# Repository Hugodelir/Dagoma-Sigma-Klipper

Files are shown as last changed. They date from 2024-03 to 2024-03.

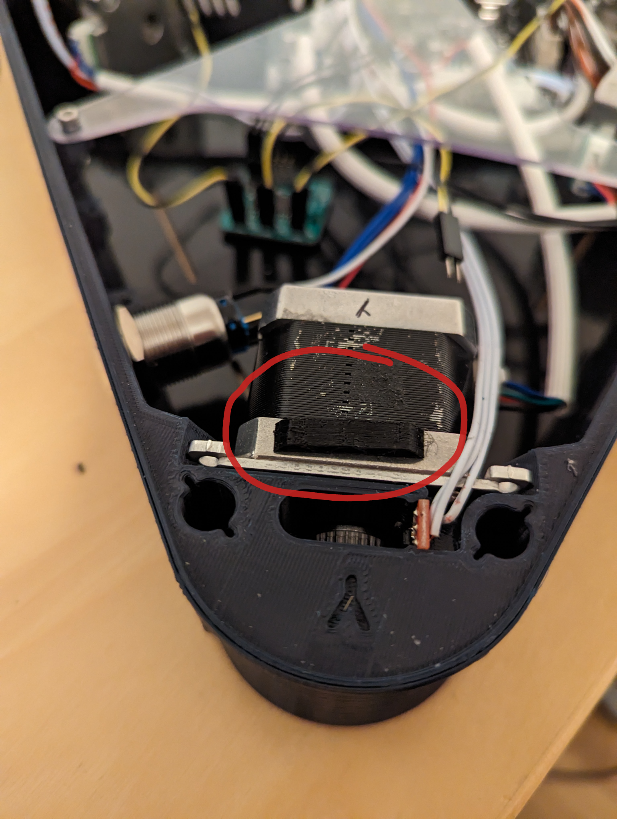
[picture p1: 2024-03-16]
Photo/Cale de rappel FSR.jpg

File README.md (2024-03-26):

Dagoma Sigma avec Klipper

ATTENTION:
Ces modifications nécessitent l'ouverture de la machine avec le risque de détériorer les capteur FSR.
Si vous envisager ces modifications vous perdez la garantie sur votre machine

Le projet à pour objectif de convertir une imprimante Dagoma Sigma utilisant comme firmware Marlin, en une imprimante utilisant comme firmeware Klipper.
afin de gagner en précision et diminuer les bruits de déplacement des chariots
Particularité de cette imprimante utilisation de 3 capteurs de force (FSR) positionnés sous le plateau afin de réaliser le bed leveling, ou Bed-mesk chez Klipper
avec utilisation d'une entrée analogique code adapté de Marlin.

4 étapes envisagé :

1- Electronique et mécanique d'origine, avec utilisation de cale de rappel afin de faire fonctionner les FSR dans la plage de commutation de l'entrée numérique.

2- Electronique et mécanique d'origine, avec ajout d'une carte pour la gestion des FSR qui produit en sortir un signal numérique tout ou rien.
Carte addtionelle utilisé : https://github.com/JohnSL/FSR_Endstop

le 1 et 2 sont des preuve de concepte, pas ou peux de gain attendu coté bruit

3- Mécanique d'origine, pour l'électronique utilisation de la dernière carte D6 avec driver TMC 2209 de chez Dagoma afin de rester dans l'echo système.
gain attendu sur le bruit en augmentant le nombre de micro-step, augmentation limité par la chip 8 bit ATMEGA2560 utiliser sur la carte

4- Mécanique d'origine, pour l'électronique utilisation de la dernière carte Fystec R4 avec la carte additionnelle pour les FSR
Gain attendu plus important sur le bruit, carte optimisé pour embarquer Klipper, form factor plus compact

Eng :
Dagoma Sigma with Klipper

WARNING:
These modifications require opening the machine with the risk of damaging the FSR sensors.
If you consider these modifications you will lose the warranty on your machine.

The project aims to convert a Dagoma Sigma printer using Marlin as firmware, into a printer using Klipper as firmware.
in order to gain precision and reduce carriage movement noise
Particularity of this printer use of 3 force sensors (FSR) positioned under the plate in order to carry out bed leveling, or Bed-mesk at Klipper
with use of an analog input code adapted from Marlin.

4 steps envisaged:

1- Original electronics and mechanics, with use of return wedge in order to operate the FSRs in the switching range of the digital input.

2- Original electronics and mechanics, with the addition of a card for managing the FSR which produces an all or nothing digital signal.
Additional card used: https://github.com/JohnSL/FSR_Endstop

1 and 2 are proof of concept, no or little gain expected in terms of noise

3- Original mechanics, for electronics use of the latest D6 card with TMC 2209 driver from Dagoma in order to remain in the echo system.
expected gain on noise by increasing the number of micro-steps, increase limited by the 8 bit ATMEGA2560 chip used on the card

4- Original mechanics, for electronics use of the latest Fystec R4 card with the additional card for FSR
Greater expected gain on noise, card optimized to embed Klipper, more compact form factor

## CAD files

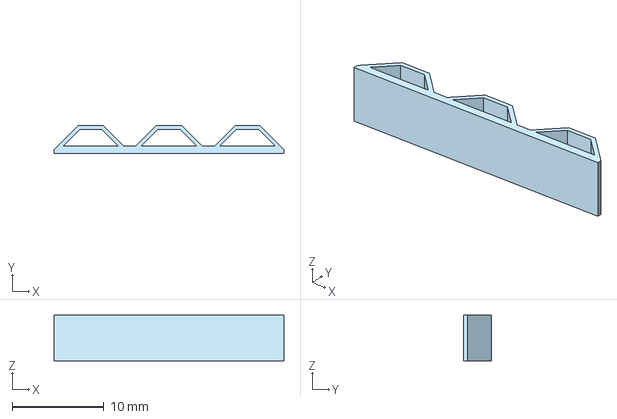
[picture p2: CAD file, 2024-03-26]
CAD/cale FSR Version long.step
25.0 x 3.00 x 5.00 mm

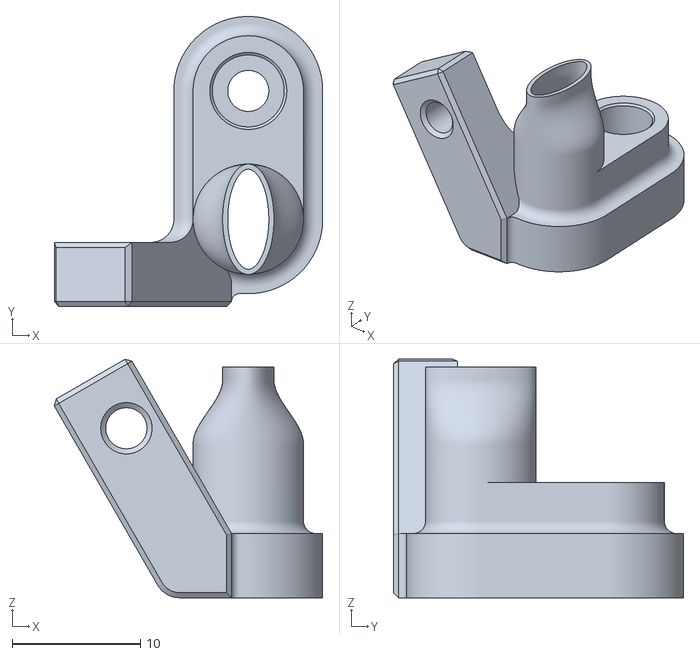
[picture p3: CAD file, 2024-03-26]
STL/Support prise V2 - Part 1.stl
20.9 x 22.6 x 18.6

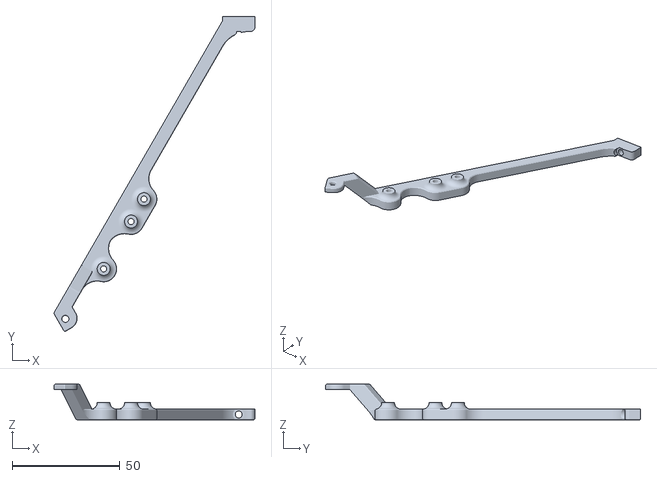
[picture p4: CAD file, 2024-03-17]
STL/support Carte D6 - Part 2.stl
93.2 x 146.3 x 16.6

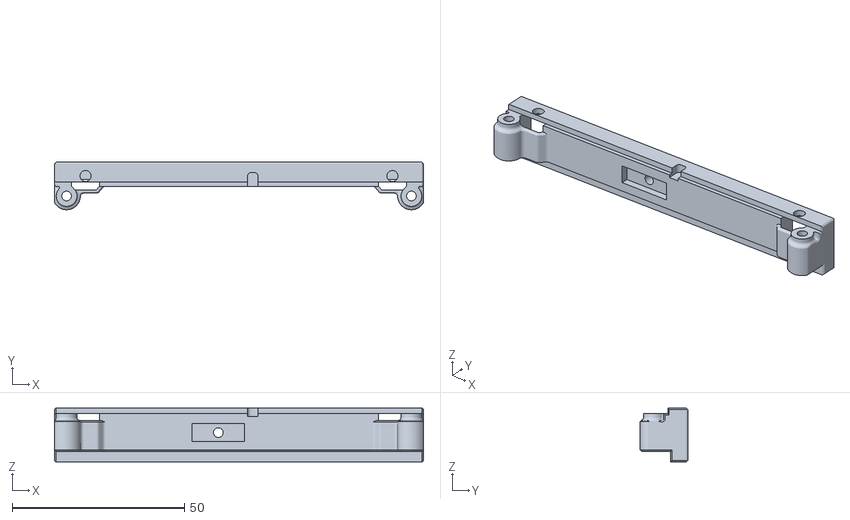
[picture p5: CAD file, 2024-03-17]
STL/support Carte D6 - Part 1.stl
107.0 x 13.8 x 15.6

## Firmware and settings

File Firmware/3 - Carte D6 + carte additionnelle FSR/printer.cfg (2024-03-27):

# !DAGOMA Sigma with Dagoma D6 board
# This file contains common pin mappings for RAMPS (v1.3 and later)
# boards. RAMPS boards typically use a firmware compiled for the AVR
# atmega2560 (though the atmega1280 is also possible).
# See docs/Config_Reference.md for a description of parameters.

# Version Electronique modifier carte Dagoma D6 + carte FSR developper par John SL + cablage adapté
# https://github.com/JohnSL/FSR_Endstop/tree/master

########################################
# Printer Settings
########################################

#  Bord Genus Dagoma
[mcu]
serial: /dev/serial/by-id/usb-Silicon_Labs_CP2102_USB_to_UART_Bridge_Controller_0001-if00-port0


[printer]
kinematics: delta

max_velocity: 250
max_accel: 1000
max_z_velocity: 100
minimum_z_position: -5
#delta_radius: 93.87
print_radius: 100
square_corner_velocity: 5.0
########################################
# Macro
########################################


[include fluidd.cfg] 

[include slicer.cfg] 

[include filament.cfg]

########################################
# A Stepper Motor & Driver Settings [X]
########################################

[stepper_a]
step_pin: PF0
dir_pin: !PF1
enable_pin: !PD7
microsteps: 32
rotation_distance: 40
full_steps_per_rotation: 200
endstop_pin: ^!PE4
#position_endstop: 232
homing_speed: 50
homing_retract_dist: 5.0
homing_retract_speed: 20
second_homing_speed: 10
#arm_length: 210
#angle: 210

[tmc2209 stepper_a]
uart_pin: PJ3
interpolate: false
#tx_pin: PJ2
diag_pin: ^PL6
uart_address: 0
run_current: 0.6
sense_resistor: 0.110
stealthchop_threshold: 999999

[endstop_phase stepper_a]
trigger_phase: 103/128

########################################
# B Stepper Motor & Driver Settings [Y]
########################################

[stepper_b]
step_pin: PF6
dir_pin: !PF7
enable_pin: !PF2
microsteps: 32
rotation_distance: 40
full_steps_per_rotation: 200
endstop_pin: ^!PE5
#arm_length: 210
#angle: 330

[tmc2209 stepper_b]
uart_pin: PJ3
interpolate: false
#tx_pin: PJ4
diag_pin: ^PG0
uart_address: 1
run_current: 0.6
sense_resistor: 0.110
stealthchop_threshold: 999999

[endstop_phase stepper_b]
trigger_phase: 78/128

########################################
# C Stepper Motor & Driver Settings [Z]
########################################

[stepper_c]
step_pin: PL3
dir_pin: !PL1
enable_pin: !PK0
microsteps: 32
rotation_distance: 40
full_steps_per_rotation: 200
endstop_pin: ^!PJ0
#arm_length: 210
#angle: 90

[tmc2209 stepper_c]
uart_pin: PJ3
interpolate: false
#tx_pin: PE6
diag_pin: ^PL2 
uart_address: 2
run_current: 0.6
sense_resistor: 0.110
stealthchop_threshold: 999999

[endstop_phase stepper_c]
trigger_phase: 112/128

########################################
# Probe Settings & Mesh Settings
########################################

[probe]
#x_offset: 0
#y_offset: 0
#z_offset: 0
sample_retract_dist: 5
pin: !PC5
speed: 10.0
# Delay 100ms before probing, for piezo probe
activate_gcode: G4 P100

[delta_calibrate]
radius: 90
horizontal_move_z: 5
Speed: 50

########################################
# Extruder & Driver Settings
########################################

[extruder]
step_pin: PA4
dir_pin: PA6
enable_pin: !PA2
microsteps: 32
rotation_distance: 24.243 #old: 48.485
nozzle_diameter: 0.400
filament_diameter: 1.750
heater_pin: PB4
sensor_type: ATC Semitec 104GT-2
sensor_pin: PK5
#control: pid
#pid_Kp: 47.66
#pid_Ki: 4.9
#pid_Kd: 115.969
min_temp: 5
max_temp: 270
min_extrude_temp : 20 # provisoire pour calibrage
max_extrude_only_distance: 900 # default is 50mm

[tmc2209 extruder]
uart_pin: PJ3
#tx_pin: PJ6
diag_pin: PD0 
uart_address: 3
run_current: 0.6
sense_resistor: 0.110
stealthchop_threshold: 0

########################################
# Fans Settings
########################################

[fan]
pin: PH4
max_power: 0.9 #old: 1.0

[heater_fan hotend_fan]
pin: PH6
heater_temp: 55.0
fan_speed: 0.9 #old: 1.0
########################################
# Bed Mesh
########################################

[bed_mesh]
speed: 50 #old: 20 | 120
horizontal_move_z: 5
mesh_radius: 75
mesh_origin: 0, 0
mesh_pps: 4, 4
round_probe_count: 5
algorithm: lagrange #old: bicubic
#bicubic_tension: 0.2
split_delta_z: .025

########################################
# Led et bouton
########################################

[output_pin LED_Bouton]
pin: !PG5
#[led button]
#red_pin: PK3
#initial_RED: 0.0
#initial_GREEN: 0.0
#initial_BLUE: 0.4
#initial_WHITE: 1

[gcode_button Bouton]
pin: ^!PG2
press_gcode:
    PAUSE
    #UNLOAD_FILAMENT 
#release_gcode:
#    Une liste de commandes G-code à exécuter lorsque le bouton est relâché.
#    Les modèles G-Code sont supportés. La valeur par défaut est de ne pas exécuter
#    de commandes lors du relâchement d'un bouton.

#*# <---------------------- SAVE_CONFIG ---------------------->
#*# DO NOT EDIT THIS BLOCK OR BELOW. The contents are auto-generated.
#*#
#*# [probe]
#*# z_offset = -0.375
#*#
#*# [extruder]
#*# control = pid
#*# pid_kp = 31.446
#*# pid_ki = 3.038
#*# pid_kd = 81.366
#*#
#*# [printer]
#*# delta_radius = 93.814061
#*#
#*# [stepper_a]
#*# angle = 209.867285
#*# arm_length = 210.000000
#*# position_endstop = 232.371192
#*#
#*# [stepper_b]
#*# angle = 329.595272
#*# arm_length = 210.000000
#*# position_endstop = 232.703093
#*#
#*# [stepper_c]
#*# angle = 90.000000
#*# arm_length = 210.000000
#*# position_endstop = 231.966446
#*#
#*# [delta_calibrate]
#*# height0 = -0.375
#*# height0_pos = 37234.000,37234.000,37234.000
#*# height1 = -0.375
#*# height1_pos = 44635.000,44635.000,33662.000
#*# height2 = -0.375
#*# height2_pos = 36756.000,48649.000,36756.000
#*# height3 = -0.375
#*# height3_pos = 33806.000,43422.000,43422.000
#*# height4 = -0.375
#*# height4_pos = 36455.000,36455.000,44990.000
#*# height5 = -0.375
#*# height5_pos = 42342.000,33999.000,42342.000
#*# height6 = -0.375
#*# height6_pos = 46711.000,36598.000,36598.000

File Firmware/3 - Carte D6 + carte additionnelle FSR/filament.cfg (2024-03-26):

########################################
# Filament Settings
########################################

[filament_switch_sensor Filament_sensor]

switch_pin: ^!PJ1 
pause_on_runout: True
runout_gcode:
    PAUSE
insert_gcode:
    LOAD_FILAMENT
#   A list of G-Code commands to execute after a filament insert is
#   detected. See docs/Command_Templates.md for G-Code format. The
#   default is not to run any G-Code commands, which disables insert
#   detection.

[gcode_macro LOAD_FILAMENT]
variable_load_distance:  820
variable_purge_distance:  25
variable_retract_distance: 2
gcode:
    {% set speed = params.SPEED|default(300) %}
    {% set max_velocity = printer.configfile.settings['extruder'].max_extrude_only_velocity  * 60 %}
    SAVE_GCODE_STATE NAME=load_state  ;Sauvegarder l'emplacement de la tete
    M117 Loading Filament ... ;Afficher le message sur l'ecran
    LOW_TEMP_CHECK ;verifier la temperature de la buse
    G91
    G92 E0
    G1 E{load_distance} F{max_velocity} # chargement rapide
    G1 E{purge_distance} F{speed} # purge
    G1 E{retract_distance} F{speed}
    M117 ;Supprimer le message de l'ecran
    RESTORE_GCODE_STATE NAME=load_state
   
    SAVE_GCODE_STATE NAME=loading_filament ;Sauvegarder l'emplacement de la tete
    M117 Loading Filament ... ;Afficher le message sur l'ecran
    #G92 E0 ;Reset extrudeur
    LOW_TEMP_CHECK ;verifier la temperature de la buse
    M83
    G1 E80 F800 ;Longueur d'extrusion
    G1 E40 F200 ;Petit extra pour purger la buse
    G1 E2 F3600 ;Petit retract pour evite que sa fuit
    G92 E0.0 ; Reset extrudeur
    M117 ;Supprimer le message de l'ecran
    RESTORE_GCODE_STATE NAME=loading_filament ;Restaurer l'emplacement de la tete

[gcode_macro UNLOAD_FILAMENT]
variable_unload_distance:  820
variable_purge_distance:  25
gcode:
    {% set speed = params.SPEED|default(300) %}
    {% set max_velocity = printer.configfile.settings['extruder'].max_extrude_only_velocity  * 60 %}
    SAVE_GCODE_STATE NAME=unload_state
    M117 Unloading Filament ... #Afficher le message sur l'ecran
    LOW_TEMP_CHECK #verifier la temperature de la buse
    G91
    G92 E0
    G1 E{purge_distance} F{speed} # purge
    G1 E-{unload_distance} F{max_velocity} # fast-unload
    RESTORE_GCODE_STATE NAME=unload_state

[gcode_macro LOW_TEMP_CHECK] ;Verification de la temperature de la buse
gcode: 
    {% set Temp_EXTRUDER = params.T_EXTRUDER|default(210)|int %}
    {% if printer.extruder.target != 0 %}
        {% if printer.extruder.temperature < printer.extruder.target %}
            M118 Heating from {printer.extruder.temperature} to {printer.extruder.target}.
            M109 S{printer.extruder.target|float} 
        {% endif %}
    {% else %}
        {% if printer.extruder.target < Temp_EXTRUDER %}
            M118 No setpoint, heating to {Temp_EXTRUDER}.
            M109 S{Temp_EXTRUDER}
        {% endif %}
    {% endif %}
